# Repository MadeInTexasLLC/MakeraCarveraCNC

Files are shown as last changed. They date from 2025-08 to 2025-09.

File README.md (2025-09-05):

# Beginner's Guide to the Makera Carvera CNC
### Everything needed to get your Carvera CNC up and running

## What This Guide Includes
### 1. Essential Bit Set (Extended) Tool Library for Fusion360 **[.tools File]**
   - Fusion360 file that includes all of the bits in the Essential Bit Set (Extended) from Makera.
   - Ready to download and import into the Tool Library tab in the Manufacture workspace of Fusion360.
   - Tools are labeled verbatim as seen on the individual bit tubes for ease of identification.
### 2. Essential Bit Set (Extended) Excel Data for Each Bit **[.ods File]**
   - Manually gathered data on all of the bits in the Essential Bit Set (Extended) from Makera.
   - Some data was not given by Makera and had to be manually measured and inputted.
   - Some data were not given AND were unmeasurable. These data points were inputted via "best-guess" approximations and highlighted in Yellow.
   - Reflects data inputted into the .tools file for Fusion360 (above).
### 3. Bit Holder/Organizer for Carvera ATC **[.stl File]**
   - A bit tube holder/organizer that slots into the Automatic Tool Changer (ATC) of the Carvera.  
   - Enchances ease of tracking and swapping of bits.
### 4. How-To Guide on Doubling Work Area (Machining Oversized Parts) on the Carvera CNC (*work-in-progress* ***)
   - A step-by-step guide on how to increase the area in which to cut your designs.
   - No additional tools needed.
### 5. Quick-Start Guide (*work-in-progress* ***)
   - Basics you need to know to get from CAD to CAM to Finishing
### 6. Workpiece Holding Guide (*work-in-progress* ***)
   - A guide to choosing the right adhesive (glue/tape) to hold down your stock during cutting.

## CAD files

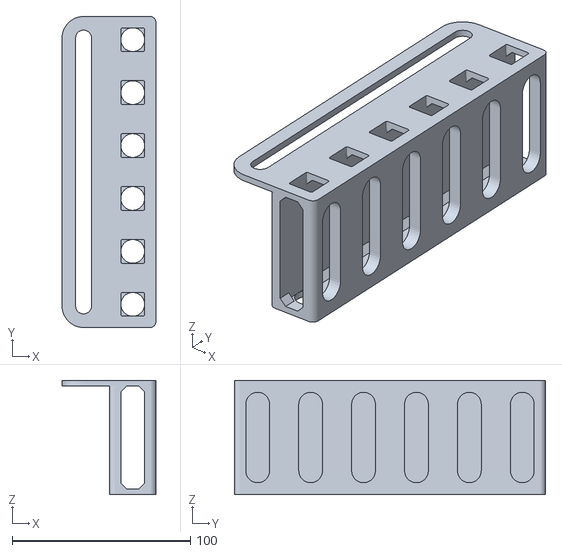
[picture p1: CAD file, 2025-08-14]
3. Bit-Holder v9.stl
52.7 x 174.6 x 64.1

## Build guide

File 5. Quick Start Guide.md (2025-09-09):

# Quick Start Guide to Carvera CNC with Fusion360 (*WIP)

## ASSUMPTIONS

### This How-To assumes that the Carvera CNC and Fusion360 is your first introduction to subtractive manufacturing and Computer Aided Manufacturing (CAM) software, respectively.

### This How-To also assumes that you have basic Computer Aided Design (CAD) experience. Whether if it's from a formal class or informal hobbyist 3D printing, this guide assumes that you have done an extrude before, so we won't be going over that. 

### This guide is focused on bringing your CAD 3D model into Fusion60 CAM to be carved by the Carvera.
  
#### Aside from that, **no information will be left out, and you won't be left behind!**  

## STEP #1: EQUIPMENT  
1. Carvera CNC (this guide could likely also be used for the Carvera Air, but it has not been formally tested on that model, yet).
2. Personal Computer (PC)
3. **optional* 3D-Printer

## STEP #2: BASIC WORKFLOW  
There are three general steps to any subtractive manufacturing proejct:
#### 1. Preparation Passes
These are the cuts that you would make to prepare a piece of stock before the actual forming passes. Some of these passes include:  
- **Surfacing passes**: cuts that flatten the surface of a piece of stock.
- **Alignment Pin passes**: cuts that bore out holes on the stock to insert dowel pins into that orient the stock onto the workbed/jig.
#### 2. Roughing Passes  
These are cuts that remove as much of the material as *efficiently* as possible. This includes efficiency in:  
- **Speed**: cutting off as much material as fast as possible. Speed is dependant on the power of your spindle and the rigidity of your machine. The Carvera is NOT a rigid machine, and I've had the bit fall out of the collet numerous times. Speed and feed optimization is essential!
- **Bit Engagement**: for example, using the full length of the bit to ensure even wear on all parts of the bit to extend life.
#### 3. Finishing Passes  
These are the detailing cuts that focus on... well... the details. 

### SUMMARY
These are the major steps that you should start thinking about before you go into CAM. Here are the flow of questions that I typically ask myself as a elf-taught hobbyist:  
1. How do I hold the stock down?  
    - Will I use adhesives? Clamps? A vacuum table? Magnets? All of the above? You can get a better answer for this in the "Workpiece Holding Guide" in this repository.  
2. How do I orient the stock accurately?  
    - Will I use alignment pins? A straight-edge?  
3. How do I set the work origin of the stock?  
    - This will determine if I get dimensionally accurate cuts on multiple pieces.  
4. What bits do I have for *roughing* passes?  
    - What is the largest bit that I have/can buy? This depends on the size of my collet, spindle power, and rigidity of machine.
5. What speeds and feeds can my machine and roughing bit handle?
    - Optimizing this part will require emipirical testing/tweaking.
6. What bits do I have for *finishing* passes?
7. What speeds and feeds can my machine and finishing bit handle?

## STEP #3: BASIC FUSION360 CAM FUNCTIONS
In this Guide, I will go over the most commonly used function (2D Pocket) and how to navigate it. Once you learn this, you can apply it to most of the other functions. 

1. Go into the Manufacture Workspace in Fusion360
2. Navigate to the Milling tab, and open the Setup function.  
    - This is where you will go to enter the dimensions of the stock, 

Navigate to the 2D section > select the dropdown menu > select 2D Pocket
Navigate to the Tool tab and under the Tool dropdown, select the bit you want to use for the operation
    - Generally, with 2D Pockets, you

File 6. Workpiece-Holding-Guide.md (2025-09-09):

# Workpiece Holding Guide - Comparison of Glues and Tapes (*WIP)

## There are many ways to hold down your work piece. 
## Which is the right way for you?

## TLDR: MY RECCOMENDATIONS
#### For **absolute beginners** (*who don't care too much as dimensional accuracy*) **who have the Carvera** (*with the auto bed leveling Z probe*), I would recommend buying:  
### A cordless hot glue gun with high temperature glue sticks  

- Hot glue applies and dries very quickly, allowing you to rapidly prototype/manufacture one piece after another.  
- The auto bed leveling of the Carvera accounts for the inconsistencies in the drying of the glue (areas that are applied first will dry faster and be thicker than areas that are applied last).  
- Hot glue is inexpensive and a cordless hot glue gun would make application more convienent (and cooler looking). 
- High temperature hot glue worked very well in keeping my pieces secure and I had no trouble using it to cut out 20 Wooden Serving Plates for a local restaurant (see BrothAndBasil repository). I used a 1/4" bit cutting softwood and the rigidity of the machine gave out first (the bit fell out of the collet) and the workpiece stayed put. 
- High temperature (NOT low temperaturea) hot glue was rigid enough to hold down the piece, but was very easy to remove after the piece was finished.
- Hot glue can be peeled off from the stock and bed, forgoing the need to buy/apply masking tape to protect either surface.

#### For **absolute beginners** (*who don't care too much as dimensional accuracy*) **who DO NOT have the Carvera** (*with the auto bed leveling Z probe*), I would recoomend buying:  
### Masking tape and Gorilla wood glue  

- A CNC that cannot auto bed level needs to have the stock as flat as possible to the bed. Gorilla wood glue has a low viscosity and can do this reasonably well for beginners.

#### For **ANYONE** that requires high dimensional accuracy, speed, and reliability; I would reccomend buying:
### Masking tape and quick drying super glue  

- Super glue dries quicker and stronger than Gorilla wood glue, but is much more expensive. I would reccomend this combination to anyone that is producing products for paying customers.  
## WORKHOLDING BASICS
The [Masking Tape and Glue Method](https://www.youtube.com/watch?v=e-coDYZCmEw) is essentially the go-to method to hold down a workpiece when physical hold downs are not available. 

Here are my experiences with various options and my reccomendations for each:

**TAPE**  
1. Scotch Masking Tape vs. Amazon Basics Masking Tape  
- I would reccomend buying name brand Scotch Tape. Their non-adhesive backing seems to be more porous and less "shiny" which allows for stronger and quicker application of glue/liquid adhesive. Additionally, the tape itself has stronger adhesion and the cost savings for buying the Amazon Basics Masking Tape is negligible.  
  
**HONORABLE MENTION**: Double-Sided Tape
- This is a convienent way to hold your workpiece, but it is not the most accurate or cost-efficient. Additionally, depending on the tape brand you buy, the double-sided tape may leave a residue that would have to be removed during post-processing.

**GLUE**
1. Loctite Super Glue: Quick-drying (<5 minutes), most expensive (comparatively), reliable
2.  Gorilla Wood Glue: Medium-drying (~30-45 minutes), second most expensive, mostly reliable
3. Elmer's School Glue: Slow-drying (~24 hours), least expensive, semi-reliable (if fully cured)
4. Gorilla Glue Sticks (High Temperature): Quick-drying (<5 minutes), second least expensive, reliable

Here is a cheat sheet on how to use the [Masking Tape and Glue Method](https://www.youtube.com/watch?v=e-coDYZCmEw):  
- Step #1: Place masking tape to the back of your stock and to the bed of the Carvera.
- Step #2: Place your chosen glue to top of the masking tape of the bed.
- Step #3: Align the masking tape placed on the stock to the masking tape placed on the bed, and then sandwich the glue between the two.

**PHYSICAL HOLD DOWNS**  
For many cases, physical hold downs are the most inexpensive (long-term) and tried-and-true form of workholding. Below are some of the possible options.  
  
**NOTE**: The Carvera does not come with some of these methods, but I am currently working on ways to modify the original Carvera machine to include some of these hold down options:

1. Clamps
2. Vice grip
3. Magnets
4. Vacuum Table

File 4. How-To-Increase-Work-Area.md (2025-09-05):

# How To Double Your Work Area / Machine Oversized Stock

## *Need more work area to cut your design?*  
## *Don’t want to buy a bigger machine?*  
### **This guide will show you how to effectively double the work area of your Carvera CNC.**  
#### *NOTE: This workaround MAY be possible with the Carvera Air CNC, but it has not been explored.*  

## ITEMS NEEDED
1. XYZ Probe (included with Carvera CNC)
2. Carvera Controller Software: v0.9.11 (included on Makera's official website)
    - There is a community version of the Carvera Controller, but the work around has not been tested for that Controller, yet.
3. Masking Tape
4. Hot Glue Sticks
5. Hot Glue Gun
6. That's it!  

## PROCEDURE
### **Step #1 Ensure stock falls within dimensions of 360mm (x) x 480mm (y) x 140mm (z)**  

stockdimensions
  
**IMPORTANT**: Technically, the stock has a maximum dimensional limit of **359mm (x) x 479mm (y) x 140mm (z)**  
- This is to ensure proper usage of the XYZ Probe, but more on this later.  

### **Step #2 Design your part in Computer-Aided Design (CAD) and process the design in Computer-Aided Manufacturing (CAM)**  

**IMPORTANT**: In your CAM software, ensure that the work origin is set to the TOP LEFT corner of your chosen stock.  
  
Work-Origin-Example  
  
**NOTE**: This specific How-To assumes that you have basic knowledge of CAD/CAM, and will NOT go into depth on best practices
regarding design.  
However, I am currently working on a Quick Start Guide for this, and will eventually include it in this repository.

### **Step #3 Adhere stock to the Carvera Bed**  
  
- Step #3a: Place masking tape to the back of your stock and to the bed of the Carvera.  

Tape

- Step #3b: Place your chosen glue to top of the masking tape of the bed.
- Step #3c: Align the masking tape placed on the stock to the masking tape placed on the bed, and then sandwich the glue between the two.  
  
**NOTE**: This How-To will not go into depth on specific glues/masking tape to use.  
The most beginner-friendly and budget-friendly option I have found specifically for the Carvera would be to use:  
**Sctoch Beige 2in Wide Masking Tape**  
**Gorilla Glue Sticks**  
**Bauer Hot Glue Gun**  
Details on this choice will be explored in the Workpiece Holding Guide in this repository.

tapestockglue

**IMPORTANT**: During Step #3c, use the side of the Automatic Tool Changer (ATC) as a make-shift straight edge to help properly align your stock whilst adhering it to the bed.  
- While this isn't *technically* the proper way to align your stock, if your stock is already planed/flat, this is a quick way to straighten your stock during adhesion.  
- The *proper* way to align your stock will be covered in the Quick Start Guide. You can also find good reference material in Point #2 of the "Other Considerations" section at the end of this file.  

pushstock1
pushstock2  

**IMPORTANT**: Ensure that the stock stays flush or within the maximum +Y of the bed and minimum -X of the bed. If material is hanging off of the bed in either direction, the XYZ probe will not function.  
**NOTE**: It is ok if there is overhang in the -Y direction of the bed.

xyaxis
              
### **Step #4 Use the manual XYZ Probe**  

[START HERE](https://www.youtube.com/watch?v=yNCbZI0ndpA&list=PL7zu0ucQCuYRTigCJ4nqRrI0TIhcHHbZl&index=8) if you've never used the XYZ Probe before, then return to Step #4a.

- Step #4a: Connect and orient your XYZ Probe to sit flush against the top LEFT corner of your stock.  

probeup
probedown

- Step #4b: Move the tool head (with the correct tool) until it is hovering over the center of the XYZ Probe.
- Step #4c: Connect the magnetic wire head to the tool head.
- Step #4d: Open Makera's Carvera Controller > Select NC Program > Open Config and Run Menu > Navigate to "Set Work Origin" > Click on "Config" > Select the "Set By XYZ Probe" Tab > Click "Run" 
- Step #4e: Once the XYZ Probe sequence has been completed, exit the "Config and Run" window, and then reopen the "Config and Run" window for new Work Origin to be saved and able to view in the window.  

configandrun1

- Step #4f: Record the current Offset from Anchor 1 that is displayed.  

zoominconfigandrun1

- Step #4g: Once the measured Offsets from the XYZ probe are recorded, go to the Auto-Set By Offset page. This is where you will manually input the Offset values you recorded earlier.  
- Step #4h: Re-Enter the recorded X-Offset as noted.  
- Step #4i: Re-Enter the Y-Offset **BUT add 50mm to that value first BEFORE inputting the value**.  
    - The XYZ Probe command touches off in the -Y direction. To correct the machine, and tell it that the edge of the material is actually in the opposite direction, we must add 50mm to the Y-Offset since that is the Edge-Edge distance of the XYZ Probe

configandrun2

**PRO TIP**: You don't need to separately record the Offset values in Step #4f. If you are able to discern the numbers from the grayed screen, you can go directly into Step #4h (see picture below). 

configandrun3

### **Step #5 THAT'S IT!!!**
Now, you can run your program to process the 1st half of the stock.  

**IMPORTANT**: Keep the lid of the Carvera **OPEN AT ALL TIMES** during the program. Your stock may run into the inside of the lid if it is closed, which could lead to stock detachment from the bed.  
  
**NOTE**: Ensure that the dust collection is turned on and functioning properly to ensure minimal spread of particulates. Using a particulate filtering mask while staying next to the machine during operation is reccomended.  

## OTHER CONSIDERATIONS  
  
1. You will have to process the stock twice if your design calls for it. Once the first pass has been completed, rotate your stock 180 degrees along the Z-Axis and repeat steps #3 - #5.  
2. This guide does not address the use of Alignment Pins. Using Alignment Pins is the proper way to ensure that your workpiece is oriented correctly for your NC Program, and you can learn more via [Austin Shaner's Fusion 350 Tutorial](https://www.youtube.com/watch?v=VPMvnzmuTOw&list=PL6PhF5oGQvMYJliRKBzRqKd98M4RR_gr1) on YouTube! This is a very beginner-friendly course and one I would reccomend you watch if it's your first time with CNC. It's the one that I used personally to understand Fusion360's CAM.  
3. If your stock is too large, the XYZ probe may not work. Since the XYZ Probe requires the movement of the tool head to touch off on the inner edges of the probe, stock that is too large or is hanging off the side of the bed will trigger the limit switches of the Carvera in the X-Y direction. That is why the maximum dimensional limit of your stock should be no larger than **359mm (x) x 479mm (y) x 140mm (z)**. This is to ensure that there is enough space for the Carvera tool head to touch off on the probe prior to activating the limit switches.

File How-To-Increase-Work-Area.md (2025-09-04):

# How To Double Your Work Area / Machine Oversized Stock

## *Need more work area to cut your design?*  
## *Don’t want to buy a bigger machine?*  
### **This guide will show you how to effectively double the work area of your Carvera CNC.**  
#### *NOTE: This workaround MAY be possible with the Carvera Air CNC, but it has not been explored.*  

## ITEMS NEEDED
1. XYZ Probe (included with Carvera CNC)
2. Carvera Controller Software: v0.9.11 (included on Makera's official website)
    - There is a community version of the Carvera Controller, but the work around has not been tested for that Controller, yet.
3. That's it!  

## PROCEDURE
### **Step #1 Ensure stock falls within dimensions of 360mm (x) x 240mm (y) x 140mm (z)**  
  
**IMPORTANT**: Technically, the stock has a maximum dimensional limit of **359mm (x) x 479mm (y) x 140mm (z)**  
- This is to ensure proper usage of the XYZ Probe, but more on this later.  

### **Step #2 Design your part in Computer-Aided Design (CAD) and process the design in Computer-Aided Manufacturing (CAM)**  

**IMPORTANT**: In your CAM software, ensure that the work origin is set to the TOP LEFT corner of your chosen stock.  
  
Work-Origin-Example  
  
**NOTE**: This specific How-To assumes that you have basic knowledge of CAD/CAM, and will NOT go into depth on best practices
regarding design.  
However, I am currently working on a quick-start guide for this, and will eventually include it in this repository.

### **Step #3 Adhere stock to the Carvera Bed**  
  
- Step #3a: Place masking tape to the back of your stock and to the bed of the Carvera.
- Step #3b: Place your chosen glue to top of the masking tape of the bed.
- Step #3c: Align the masking tape placed on the stock to the masking tape placed on the bed, and then sandwich the glue between the two.

**IMPORTANT**: During Step #3c, use the side of the Automatic Tool Changer (ATC) as a make-shift straight edge to help properly align your stock whilst adhering it to the bed.  
**NOTE**: This How-To will not go into depth on specific glues/masking tape to use.  
The most beginner-friendly and budget-friendly option I have found specifically for the Carvera would be to use:  
**Sctoch Beige 2in Wide Masking Tape**  
**Gorilla Glue Sticks**  
**Bauer Hot Glue Gun**  
Details on this choice will be explored in a separate file in this repository.
              
### **Step #4 Use the manual XYZ Probe**  

[START HERE](https://www.youtube.com/watch?v=yNCbZI0ndpA&list=PL7zu0ucQCuYRTigCJ4nqRrI0TIhcHHbZl&index=8) if you've never used the XYZ Probe before, then return to Step #4a.

- Step #4a: Connect and orient your XYZ Probe to sit flush against the top LEFT corner of your stock.  
- Step #4b: Move the tool head (with the correct tool) until it is hovering over the center of the XYZ Probe.
- Step #4c: Connect the magnetic wire head to the tool head.
- Step #4d: Select your NC Program, and then run the XYZ Probe command from the Config Menu.  
- Step #4e: Once the XYZ Probe command has been completed, exit the File window, and reopen the window to view changes in the stock origin.  
- Step #4f: Take note of the current Offset from Anchor 1 that is displayed.
- Step #4g: Once the measured Offsets from the XYZ probe are recorded, go to the Manual Offset Input page.
- Step #4h: Re-Enter the recorded X-Offset as noted.
- Step #4i: Re-Enter the Y-Offset **BUT add 50mm to that value first BEFORE inputting the value**.
    - The XYZ Probe command touches off in the -Y direction. To correct the machine, and tell it that the edge of the material  
        is actually in the opposite direction, we must add 50mm to the Y-Offset since that is the Edge-Edge distance of the XYZ Probe

### **Step #5 THAT'S IT!!!**
Now, you can run your program to process the 1st half of the stock.  

**IMPORTANT**: Keep the lid of the Carvera **OPEN AT ALL TIMES** during the program. Your stock may run into the inside of the lid if it is closed, which could lead to stock detachment from the bed.  
  
**NOTE**: Ensure that the dust collection is turned on and functioning properly to ensure minimal spread of particulates. Using a particulate filtering mask while staying next to the machine during operation is reccomended.  

## OTHER CONSIDERATIONS  
  
1. You will have to process the stock twice if your design calls for it. Once the first pass has been completed, rotate your stock 180 degrees along the Z-Axis and repeat steps #3 - #5.  
2. This guide does not address the use of Alignment Pins. Using Alignment Pins is the proper way to ensure that your workpiece is oriented correctly for your NC Program, and you can learn more via [Austin Shaner's Fusion 350 Tutorial](https://www.youtube.com/watch?v=VPMvnzmuTOw&list=PL6PhF5oGQvMYJliRKBzRqKd98M4RR_gr1) on YouTube! This is a very beginner-friendly course and one I would reccomend you watch if it's your first time with CNC. It's the one that I used personally to understand Fusion360's CAM.  
3. If your stock is too large, the XYZ probe may not work. Since the XYZ Probe requires the movement of the tool head to touch off on the inner edges of the probe, stock that is too large or is hanging off the side of the bed will trigger the limit switches of the Carvera in the X-Y direction. That is why the maximum dimensional limit of your stock should be no larger than **359mm (x) x 479mm (y) x 140mm (z)**. This is to ensure that there is enough space for the Carvera tool head to touch off on the probe prior to activating the limit switches.

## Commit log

2025-07-10 Upload first excel about CNC bit data
    Uploading Essential Bit Set (Extended) data on each one of the bits included. Manually inputted, and will update as I use the bits for projects.
    [Essential Bit Set (Extended) Tool Library for Each Bit.ods]
2025-07-10 Delete Essential Bit Set (Extended) Tool Library for Each Bit.ods
    removed to rename the file
    [Essential Bit Set (Extended) Tool Library for Each Bit.ods]
2025-08-14 Bit Holder for Carvera ATC
    Side hanging bit holder/organizer for the ATC of the Carvera
    [Bit-Holder v9.stl]
2025-09-05 reformat organization of files
    [2. Essential Bit Set (Extended) Excel Data for Each Bit.ods, 3. Bit-Holder v9.stl]
2025-09-09 reformat Glue section
